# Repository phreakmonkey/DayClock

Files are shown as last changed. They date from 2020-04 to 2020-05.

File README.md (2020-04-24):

## DayClock
### What day is it?!?!



A simple "clock" to tell you what day it is.  It utilizes the NTPtimeESP library (https://github.com/SensorsIot/NTPtimeESP) to determine the day of the week.

Parts list:
  - Wemos D1 Mini (or suitable ESP8266 dev board)
  - "9g" Micro Servo (standard 12mm x 23mm)
  - 3D printed STL files in this repo. (STL models are in millimeters)

Connect the servo to the Wemos D1 as shown:

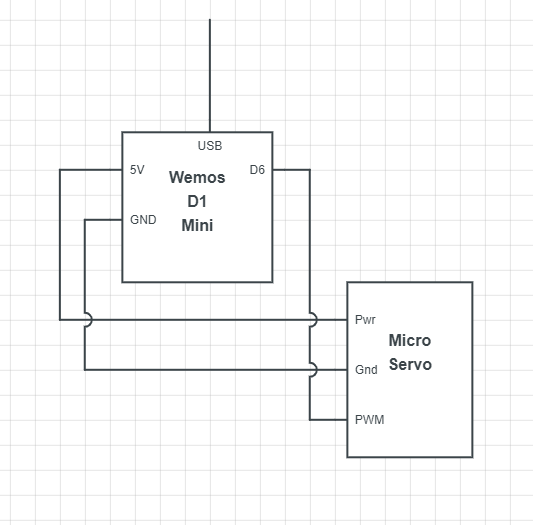
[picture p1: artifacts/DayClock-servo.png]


Edit DayClock.cpp to set your WiFi SSID, Password, and timezone (UTC_OFFSET)
Compile & upload to the ESP8266.  (Personally, I use PlatformIO.  YMMV with the Arduino IDE.)

When the unit first powers on it will cycle the servo to each of the 7 "day" positions.  Make a note of any that you want to adjust and increase/decrease the "degrees" in the source file appropriately.

The program will output some diagnostic info (Wifi connection status, current time & date when it syns with NTP, &etc) via the USB serial port at 115200 baud.

Have fun!

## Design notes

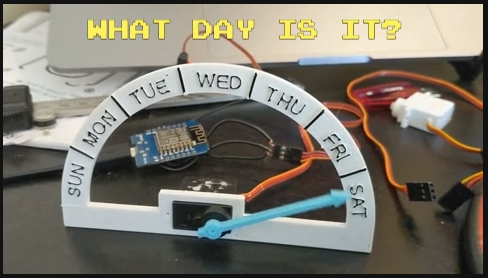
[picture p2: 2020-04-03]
artifacts/Dayclock-image.png

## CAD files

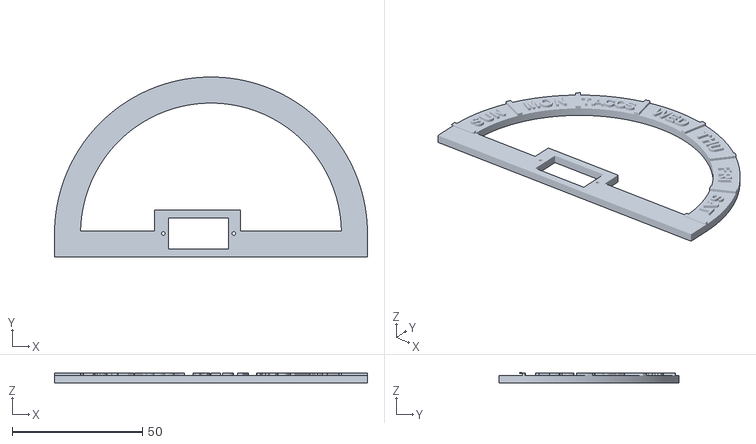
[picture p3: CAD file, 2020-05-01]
DayClock-TacoTuesday.stl
120.0 x 69.0 x 4.00

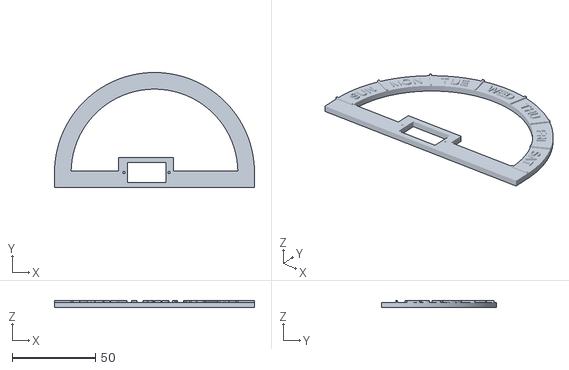
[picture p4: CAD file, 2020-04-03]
DayClock.stl
120.0 x 69.0 x 4.00

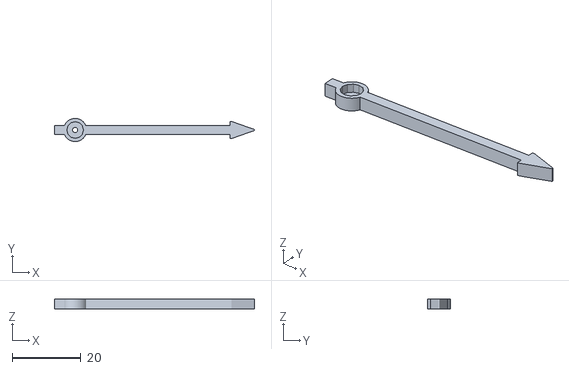
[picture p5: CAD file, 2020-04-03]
DayClock-hand.stl
58.2 x 6.75 x 3.00

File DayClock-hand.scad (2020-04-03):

difference() {
    union() {
        cylinder(r=6.75/2, h=3, $fn=120);
        translate([-6, -1.25, 0]) cube([52,2.5,3]);
        hull() {
            translate([45, -2.5, 0]) cube([.5, 5, 3]);
            translate([52, 0, 0]) cylinder(r=.2, h=3, $fn=120);
        }
    }
    translate([0,0,1.1]) cylinder(r=4.85/2, h=2, $fn=12);
    translate([0,0,-.1]) cylinder(r=.75, h=4, $fn=120);
}

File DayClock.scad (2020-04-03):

module rtext(st) {
    width = 104;
    thickness = 4;
    len = width / 2;
    chars = len(st) + 1;
    degrees = 180;
    ang = degrees/chars;

    #rotate(degrees/2) {
        for (i = [1: chars]) {
            linear_extrude(thickness)
              translate([len*sin(i*ang), len*cos(i*ang), 0])
                rotate(-ang*i)
                  text(st[i-1],size=5);
        }
    }
}

module servo_mount() {
  difference() {
    cube([3,33,18]);
    translate([-.2,4.5,3]) cube([5,23,12]);
    translate([-.2,2.5,9]) rotate([0,90,0]) cylinder(r=.7,h=5,$fn=64);
    translate([-.2,29.5,9]) rotate([0,90,0]) cylinder(r=.7,h=5,$fn=64);
  }
}

// ARC:
difference() {
    union() {
        cylinder(r=60, h=3, $fn=180);
        for (i=[0: 25.7: 180]) {
            rotate([0,0,i]) translate([0, -.5, 0]) cube([60, 1, 4]);
        }
    }
    translate([0,0,-.1]) cylinder(r=50, h=5, $fn=180);
    translate([-61,-61,-.1]) cube([122, 61, 4]);
}

translate([11.25, 9,0]) rotate([0, -90, 90]) servo_mount();

translate([-60, -9, 0]) cube([40, 10, 3]);
translate([10, -9, 0]) cube([50, 10, 3]);

// TEXT:
rtext("SUN                               ");
rtext("    MON                      ");
rtext("          TUE                     ");
rtext("                    THU           ");
rtext("                           FRI      ");
rtext("                             SAT ");
#translate([-7,52,0])
  linear_extrude(4) text("WED", size=5);

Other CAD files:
DayClock-bold.stl

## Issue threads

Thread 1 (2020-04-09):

servo vibration on pc

ScottTu, 2020-04-09:
not really an issue, just something to note. my servo was vibrating and went through the code thinking it was setting the position over and over but it turned out to just be noise on the pc's usb power line. prob needs a ferite core if you run it from pc usb power. the issue went away with a wall charger.

phreakmonkey, 2020-04-09:
Ah yes... Servo Jitter.  I knew this was going to be an issue for some people.  Hobby servos are notoriously low-quality, and some of them "jitter" even with clean power and a consistent position pulse being sent.   (As long as the servo is powered on you DO have to keep sending the position to it, in the form of a PWM pulse.  That's what the Arduino Servo.h library abstracts away for you.)

As you found, sometimes the jitter can be caused by noisy voltage.  Other times it can just be inherent in the inexpensive potentiometer used internally to determine the servo position.

Sometimes it happens in one position but not others, so "nudging" the servo a degree left or right will make it quit.

The **real** solution to servo jitter would be to power off the servo between movements.  We can't run the power pin directly from an IO pin since they only source 3.3V and 12ma.   So, we'd need to run the servo power through a transistor (e.g. a 2N3904 or 2N3906) driven to saturation and acting as a switch.  Then you'd just add digitalWrite HIGH / LOW statements to the moveto() code to switch the servo on/off before & after moving.  I considered this, but decided that keeping the project super simple, with the possibility of jitter as the trade-off.  ;)

phreakmonkey, 2020-04-09:
[change my mind - leaving open for visibility in case anyone else is interested / curious]

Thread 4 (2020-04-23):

Opening STL Files

lokijota, 2020-04-23:
Hi,

I'm having trouble opening the STL files. I've tried a few online tools like https://best-form.de/en/shop/individual-3d-print/ , https://www.viewstl.com/ or https://3dviewer.net/ and all of them refuse to open and say the file is incorrect.

Help?

lokijota, 2020-04-23:
My mistake :p .

Closed 2020-04-23.

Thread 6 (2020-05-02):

No issue - just praise

thieleke, 2020-05-02:
I saw your design on Hackaday (https://hackaday.com/2020/04/08/what-day-is-it/) and was immediately inspired by your work.  I wanted to continue on that path and added a temperature/humidity sensor and CO2 sensor, as well as a web server that lets me log my basement office space's air quality.

Thank you for providing the inspiration for my subsequent work (https://github.com/thieleke/dayclock) and stay safe!

phreakmonkey, 2020-05-03:
Awesome.

What the hell is that in the background?  Looks almost like an IMSAI or
ALTAIR 8800, but different...

On Sat, May 2, 2020 at 4:25 PM Jeff Thieleke <notifications@github.com>
wrote:

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

jeffthieleke-wf, 2020-05-03:
It is awesome.  https://obsolescence.wixsite.com/obsolescence/pidp-11

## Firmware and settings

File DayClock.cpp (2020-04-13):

/** DayClock v.8 - Written 2020.04.01 by K.C. Budd 
 *              Phreakmonkey Enterprises
 *              https://www.thingiverse.com/
 * 
 * Because during the COVID-19 Global Pandemic, it's hard to remember what day it is.
 * 
 * Requres: NTPtimeESP library (https://github.com/SensorsIot/NTPtimeESP)
 **/

#include <Arduino.h>
#include <Servo.h>
#include <NTPtimeESP.h>

NTPtime NTPpool("0.us.pool.ntp.org");   // Choose server pool as required
const char *ssid       = "SSID";        // Set you WiFi SSID
const char *password   = "PASSWORD";    // Set you WiFi password
const float UTC_OFFSET = -8.0;          // TZ Offset in X.Y decimal hours.  (e.g -5.0 US EST, -8.0 US PST)
const int DST          = 2;             // 0 = None, 1 = European Summer Time, 2 = USA DST
const int ServoPin     = D6;            // Which Arduino pin is the servo connected to?

// Servo degree positons
// Adjust as needed:  Sun  Mon  Tue  Wed  Thu  Fri  Sat
const int day[7] =   {160, 133, 110,  87,  67,  44,  20};

// If your servo turns the "wrong direction" just reverse the order by 
// commenting out the above and using the following instead.
// Adjust as needed:  Sun  Mon  Tue  Wed  Thu  Fri  Sat
//const int day[7] =   { 20,  44,  67,  87, 110, 133, 160};

const int servodelay = 10;  // Servo speed, smaller is faster (default: 10)

// Interval Timer
unsigned long itimer = 0;
unsigned long interval = 21600000;  // Check NTP every six hours

// Rollover Timer
unsigned long rtimer = 0;
unsigned long rollover = 0;

strDateTime dateTime;
Servo myservo;
uint8_t today = 7;


void moveto(uint8_t d) {
  uint8_t idx = d - 1;
  int curpos = myservo.read();
  if (day[idx] > curpos) {
    for (int i=curpos; i < day[idx]; i++) {
      myservo.write(i);
      delay(servodelay);
    }
  } else {
    for (int i=curpos; i > day[idx]; i--) {
      myservo.write(i);
      delay(servodelay);
    }
  }
}

void setup() {
  // Startup Dance:
  myservo.attach(ServoPin);
  for (int i=1; i < 8; i++) {
    moveto(i);
    delay(1500);
  }
  Serial.begin(115200);
  Serial.println();
  Serial.println("Booted");
  Serial.println("Connecting to Wi-Fi");

  WiFi.mode(WIFI_STA);
  WiFi.begin (ssid, password);
  while (WiFi.status() != WL_CONNECTED) {
    Serial.print(".");
    delay(500);
  }
  Serial.println("WiFi connected");
}

void loop() {
  unsigned long currentMillis = millis();

  if (rtimer && (unsigned long)(currentMillis - rtimer) >= rollover) {
    Serial.println("Rollover!");
    today++;
    if (today == 8) today = 1;  // Can't use modulus for 1-7
    moveto(today);
    rtimer = currentMillis;
    rollover = 86400000;
  }

  if ((unsigned long)(currentMillis - itimer) >= interval || !dateTime.valid) {
    dateTime = NTPpool.getNTPtime(UTC_OFFSET, DST);
    if(dateTime.valid) {
      itimer = currentMillis;
      int hremain = 0, minremain = 0, secremain = 0;
      hremain = 23 - dateTime.hour;
      minremain = 59 - dateTime.minute;
      secremain = 60 - dateTime.second;    
      
      if (today != dateTime.dayofWeek) {
        today = dateTime.dayofWeek;  // 1-7 because stupid
        moveto(today);
      }

      // Update rollover counter with more recent sync:
      unsigned long rolloversec = hremain * 3600 + minremain * 60 + secremain;
      rollover = rolloversec * 1000;
      rtimer = millis();

      NTPpool.printDateTime(dateTime);
      Serial.print("Seconds remaining: ");
      Serial.println(rolloversec);
    }
  }
}

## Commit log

2020-04-13 Fixed issue where if run on Saturday, pointer would not go to Sunday
    [DayClock.cpp]
2020-04-13 Example for both servo directions
2020-05-01 Bold text models
    [DayClock-TacoTuesday.stl, DayClock-bold.stl]
